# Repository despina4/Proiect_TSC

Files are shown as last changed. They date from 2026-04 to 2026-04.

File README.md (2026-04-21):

# Documentatie Hardware - Proiect Wearable / Smartwatch nRF52840

## 1. Diagrama Bloc

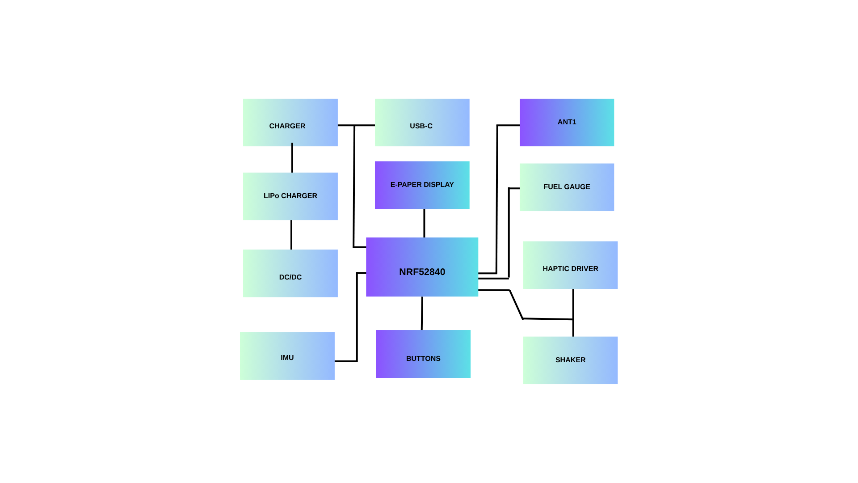
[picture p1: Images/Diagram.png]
Diagrama_bloc


Diagrama ilustreaza doua fluxuri principale:
*   **Fluxul de Alimentare:** De la portul USB-C, prin circuitul de incarcare, catre baterie si apoi prin convertorul DC/DC catre restul componentelor.
*   **Fluxul de Date/Control:** Centrat pe microcontrolerul nRF52840, care comunica cu senzorii, display-ul.

---

## 2. Bill of Materials (BOM)

Tabelul de mai jos contine modulele principale folosite in proiect, impreuna cu link-uri pentru achizitie si specificatii tehnice.

| Nume produs | Ref | Link achizitionare | Datasheet |
| :--- | :--- | :--- | :--- |
| **nRF52840-QIAA** | U1 | [Component Search Engine](https://componentsearchengine.com/part-view/NRF52840-QIAA-R/Nordic%20Semiconductor) | [Datasheet](https://4donline.ihs.com/images/VipMasterIC/IC/NRSA/NRSA-S-A0021008244/NRSA-S-A0021008244-1.pdf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) |
| **BQ25180YBGR** | IC1 | [Component Search Engine](https://componentsearchengine.com/search?term=BQ25180YBGR) | [Datasheet](https://analytics.supplyframe.com/trackingservlet/track/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) |
| **DRV2605YZFR** | IC2 | [Component Search Engine](https://componentsearchengine.com/search?term=DRV2605YZFR) | [Datasheet](https://analytics.supplyframe.com/trackingservlet/track/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) |
| **BMA423** | IC3 | [Component Search Engine](https://componentsearchengine.com/search?term=bma423) | [Datasheet](https://analytics.supplyframe.com/trackingservlet/track/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) |
| **RT6160AWSC** | IC9 | [Component Search Engine](https://componentsearchengine.com/part-view/RT6160AWSC/RICHTEK) | [Datasheet](https://analytics.supplyframe.com/trackingservlet/track/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) |
| **MAX17048G+** | U3 | [Component Search Engine](https://componentsearchengine.com/part-view/MAX17048G%2B/Analog%20Devices) | [Datasheet](https://analytics.supplyframe.com/trackingservlet/track/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) |
| **USB4105-GF-A** | J4 | [SnapMagic](https://www.snapeda.com/parts/USB4105-GF-A/GCT/view-part/?ref=search&t=USB4105-GF-A&ab_test_case=b) | [Datasheet](https://www.snapeda.com/parts/USB4105-GF-A/GCT/datasheet/) |
| **503480-2400** | J1 | [Component Search Engine](https://componentsearchengine.com/part-view/503480-2400/Molex) | [Datasheet](https://analytics.supplyframe.com/trackingservlet/track/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) |
| **EVP-AKE31A** | SW_x | [Component Search Engine](https://componentsearchengine.com/part-view/EVPAKE31A/Panasonic) | [Datasheet](https://analytics.supplyframe.com/trackingservlet/track/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) |
| **2450AT18B100E** | ANT1 | [Component Search Engine](https://componentsearchengine.com/part-view/2450AT18B100E/JOHANSON%20TECHNOLOGY) | [Datasheet](https://analytics.supplyframe.com/trackingservlet/track/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) |
| **02016D105KAT4A** | Cap | [Component Search Engine](https://componentsearchengine.com/part-view/02016D105KAT4A/Kyocera%20AVX) | [Datasheet](https://analytics.supplyframe.com/trackingservlet/track/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) |
| **0402B472K500NT** | Cap | [Component Search Engine](https://componentsearchengine.com/part-view/0402B472K500NT/Guangdong%20Fenghua%20Advanced%20Tech) | [Datasheet](https://analytics.supplyframe.com/trackingservlet/track/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) |
| **0603N101Z160PHT** | Cap | [Component Search Engine](https://componentsearchengine.com/part-view/0603N101Z160PHT/Knowles) | [Datasheet](https://analytics.supplyframe.com/trackingservlet/track/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) |
| **MBR0530** | D_x | [Component Search Engine](https://componentsearchengine.com/part-view/MBR0530/MCC) | [Datasheet](https://analytics.supplyframe.com/trackingservlet/track/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) |
| **USBLC6-2SC6Y** | D3 | [Component Search Engine](https://componentsearchengine.com/part-view/USBLC6-2SC6Y/STMicroelectronics) | [Datasheet](https://analytics.supplyframe.com/trackingservlet/track/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) |
| **HT7750A SOT23-3** | Q1 | [Component Search Engine](https://componentsearchengine.com/part-view/HT7750A%20SOT23-3/Holtek) | [Datasheet](#) |
| **SI1308EDL** | Q3 | [Component Search Engine](https://componentsearchengine.com/part-view/SI1308EDL-T1-GE3/Vishay) | [Datasheet](https://analytics.supplyframe.com/trackingservlet/track/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) |
| **NX2016SA-32MHZ** | X1 | [Component Search Engine](https://componentsearchengine.com/part-view/NX2016SA-32MHZ-EXS00A-CS11336/NDK) | [Datasheet](https://analytics.supplyframe.com/trackingservlet/track/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) |
| **ABS07-32.768KHZ** | X2 | [Component Search Engine](https://componentsearchengine.com/part-view/ABS0732768KHZT/ABRACON) | [Datasheet](https://analytics.supplyframe.com/trackingservlet/track/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) |
| **WE-TPC 4828** | L5 | [SnapMagic](https://www.snapeda.com/parts/744043004/W%C3%BCrth%20Elektronik/view-part/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) | [Datasheet](https://www.snapeda.com/parts/744043004/W%C3%BCrth%20Elektronik/datasheet/) |
| **MLP2016SR47M** | L7 | [Component Search Engine](https://componentsearchengine.com/part-view/MLP2016SR47MT0S1/TDK) | [Datasheet](https://analytics.supplyframe.com/trackingservlet/track/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) |

---
## 3. Detalii Tehnice Hardware

### A. Centrul de Procesare si Comunicatie
*   **MCU Nordic nRF52840:**
    - System on Chip -> gestioneaza stack-ul de comunicatie Bluetooth 5.0, procesarea semnalelor de la senzori si controlul logic al alimentarii.
*   **Conectivitate:**
    - Include ANT1 pentru transmisiuni BLE stabile, cu o zona de decupare dedicata in planul de masa.

### B. Subsistemul de Afisare si Interactiune (UI/UX)
*   **Tehnologie E-Paper (SPI):** 
    - Ecran bi-stabil pentru a elimina consumul de energie in mod static. Imaginea ramane pe ecran fara alimentare (economisire pana la refresh).
*   **Feedback Tactil (I2C):** 
    - **DRV2605** actioneaza un motor de vibratii tip ERM, astfel permite  notificari tactile.
*   **Control Manual:** 
     - Navigarea este realizata prin 3 butoane mecanice, switch-urile.

### C. Detectie Miscare si Monitorizare
*   **BMA423:** 
    - Senzor inteligent -> pedometru 
*   **FuelGauge:**-> determina procentul de incarcare al bateriei
### D. Alimentare + Protectie
* **Charger** 
    - Incarca bateria prin USB-C si o protejeaza.
* **DC/DC**
    -  Mentine curentul fix la 3.3V pentru toate piesele.
* **Dioda**
    - Protejeaza placa de socuri electrice la mufa USB
---

## 4. Alocare Pini nRF52840

| Pin | Semnal | Functionalitate |
| :--- | :--- | :--- |
| **P0.00 / 0.01** | XL1 / XL2 | Conexiune cristal  |
| **P0.02** | SCK | SPI Clock  |
| **P0.03** | MOSI | SPI Data MOSI |
| **P0.05** | EPD_CS | SPI Chip Select |
| **P0.08** | IMU_INT1 | Intrerupere 1 -> senzor BMA423 |
| **P0.10** | ALERT | Semnal de alerta sistem |
| **P0.15** | EPD_DC | SPI Data/Command |
| **P0.16** | EPD_RST | Reset hardware Display |
| **P0.17** | EPD_BUSY | Status Display|
| **P0.18** | RESET | Reset sistem  |
| **P1.00** | SW_ENT | Buton ENTER|
| **P0.13** | SW_UP | Buton UP|
| **P0.14** | SW_DN | Buton DOWN|
| **P0.11** | PMIC_INT | Intrerupere management baterie|
| **P0.12** | HAPTIC_EN | Semnal Enable driver haptic|
| **P1.08** | IMU_INT2 | Intrerupere 2 -> senzor BMA423|
| **P0.06** | SDA | Date I2C |
| **P0.07** | SCL | Clock I2C. |

---
## 5. Design 
- Rutarea am realizat-o manual, pe 3 layere :TOP, BOTTOM, GND.
- In momentul generarii planului de masa (GND copper pour), am creat o zona de cutout polygon in dreptul antenei.Am luat aceasta masura  pentru a preveni ecranarea sau  detuning ul antenei de catre planul de cupru adiacent.

## 6. Erori DRC marcate ca APPROVED
Din cauza dimensiunilor foarte mici, am dat approve la cateva erori manual, ignorand erorile DRC :

*   **Copper Clearance (IC2):** Am acceptat 4 erori pentru a permite width de 0.3 mm pentru power traces (VBUS, 3V3).
*   **Via Overlap:** Pentru a conecta componentele din mijlocul componenetelor, cat si cele care nu erau accesibile altfel, am fost constransa sa pun via-uri peste componenta. 
---

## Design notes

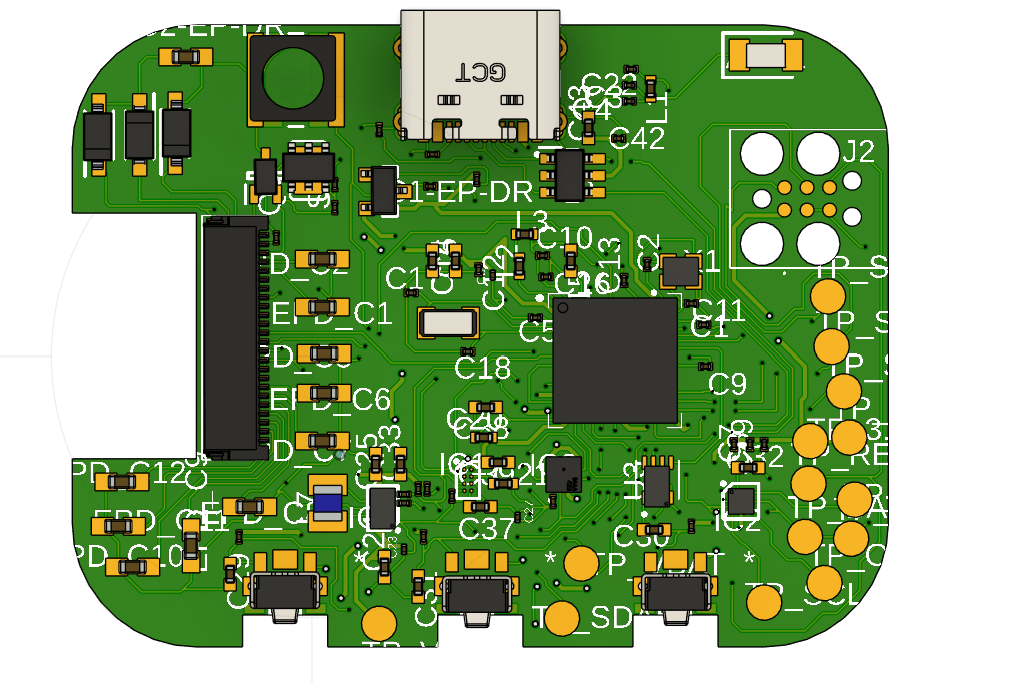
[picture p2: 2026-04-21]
Images/top_view_3D.png

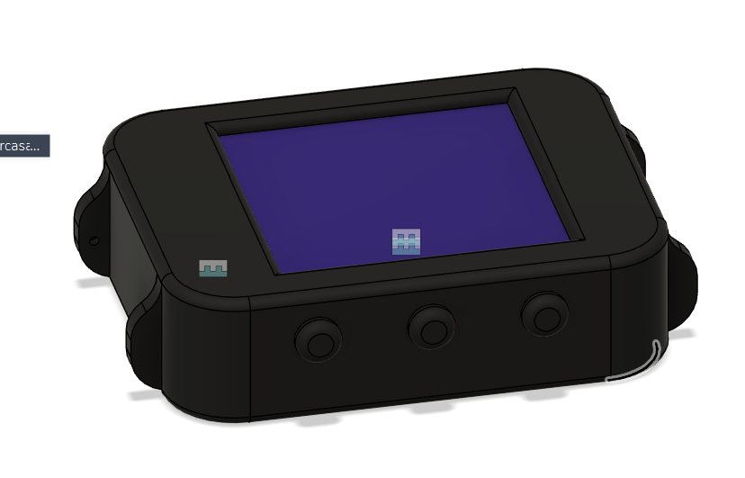
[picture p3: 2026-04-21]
Images/pcb_3d_locked - Copy.png

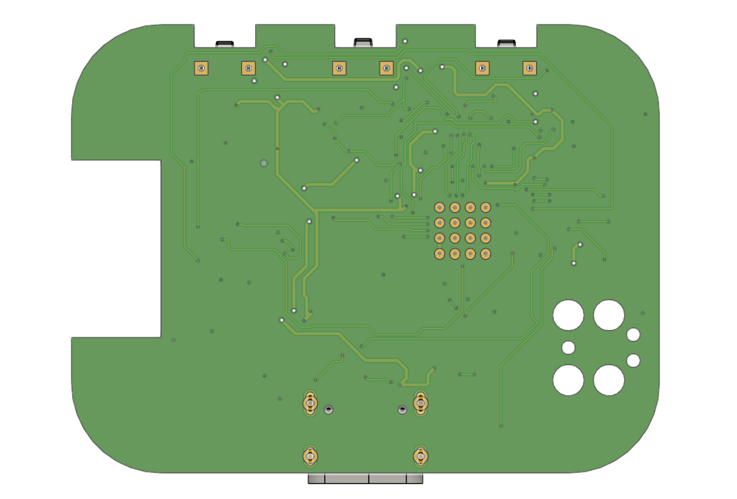
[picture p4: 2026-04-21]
Images/bottom_view_3D.png

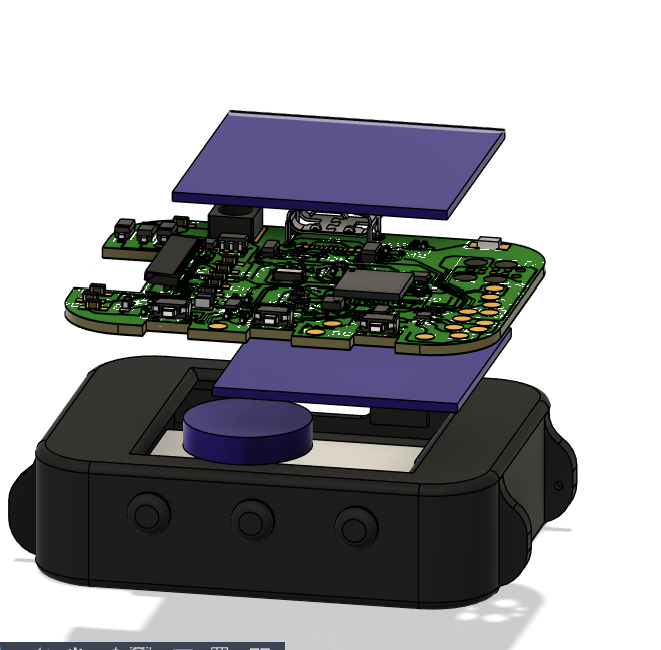
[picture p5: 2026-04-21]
Images/PCB_3D_complete_exterior_view.png

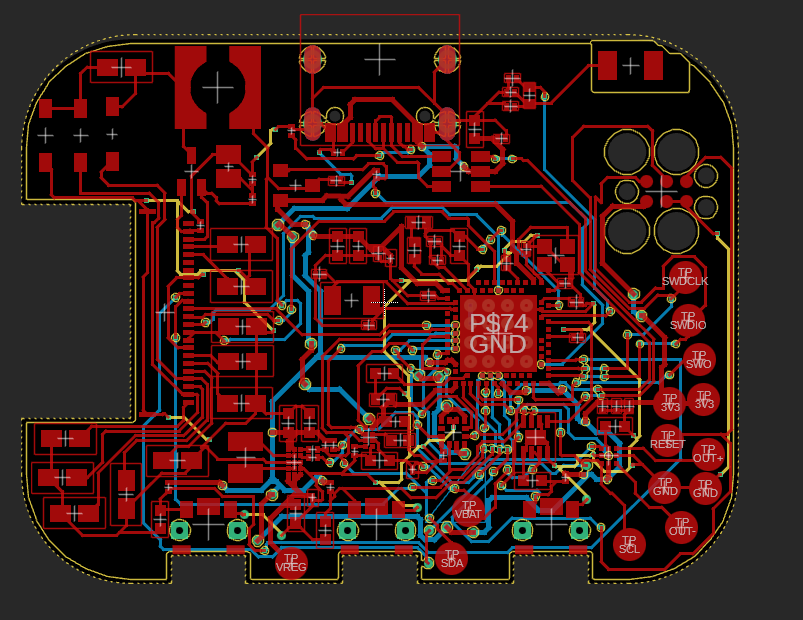
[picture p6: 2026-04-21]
Images/pcb_rutare.png

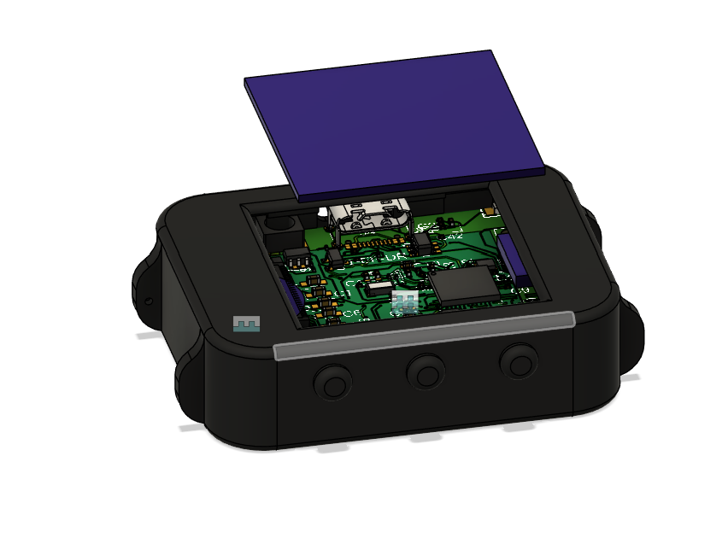
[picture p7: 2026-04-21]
Images/PCB_3D_complete.png

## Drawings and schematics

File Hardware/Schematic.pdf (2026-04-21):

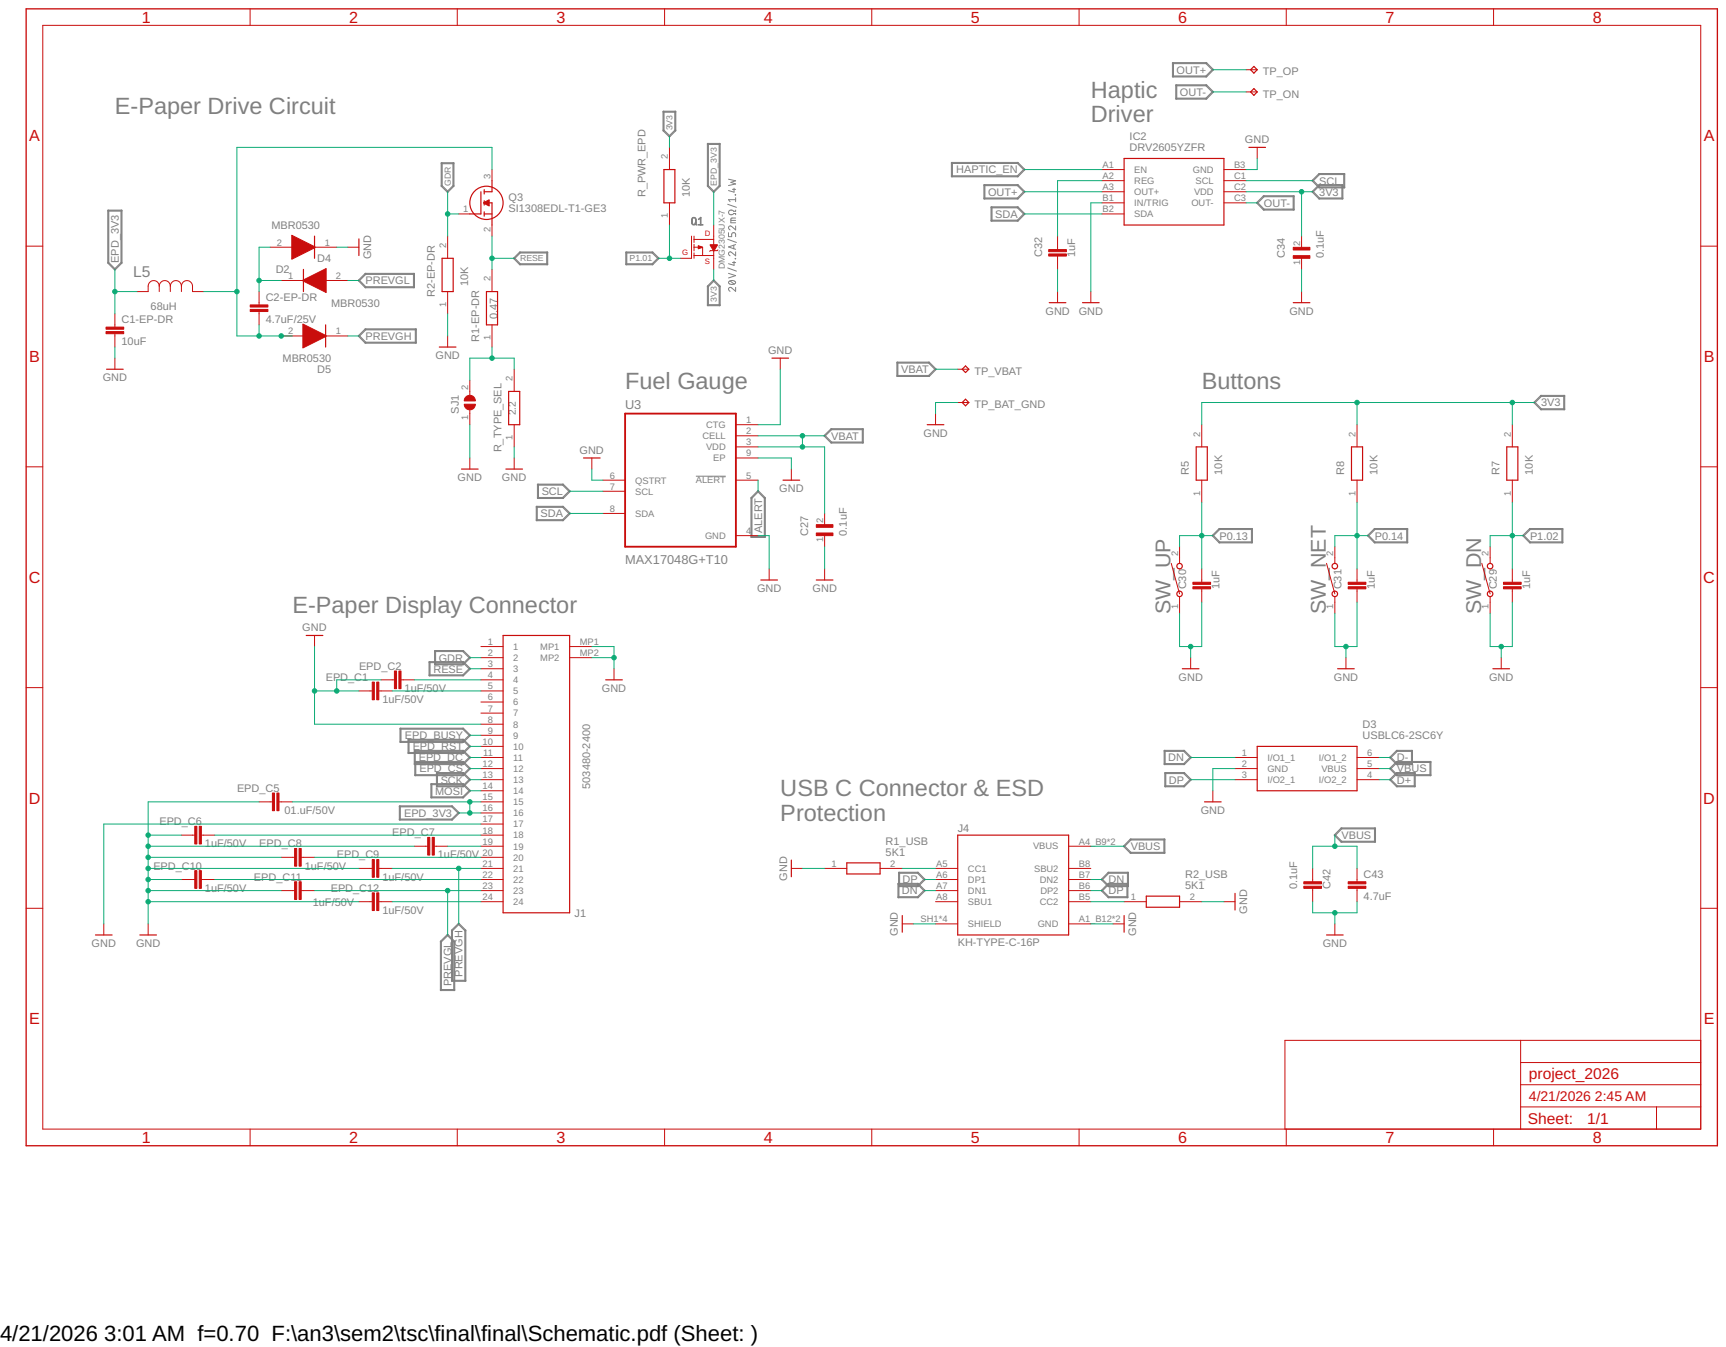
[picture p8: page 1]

4/21/2026 3:01 AM f=0.70 F:\an3\sem2\tsc\final\final\Schematic.pdf (Sheet: )

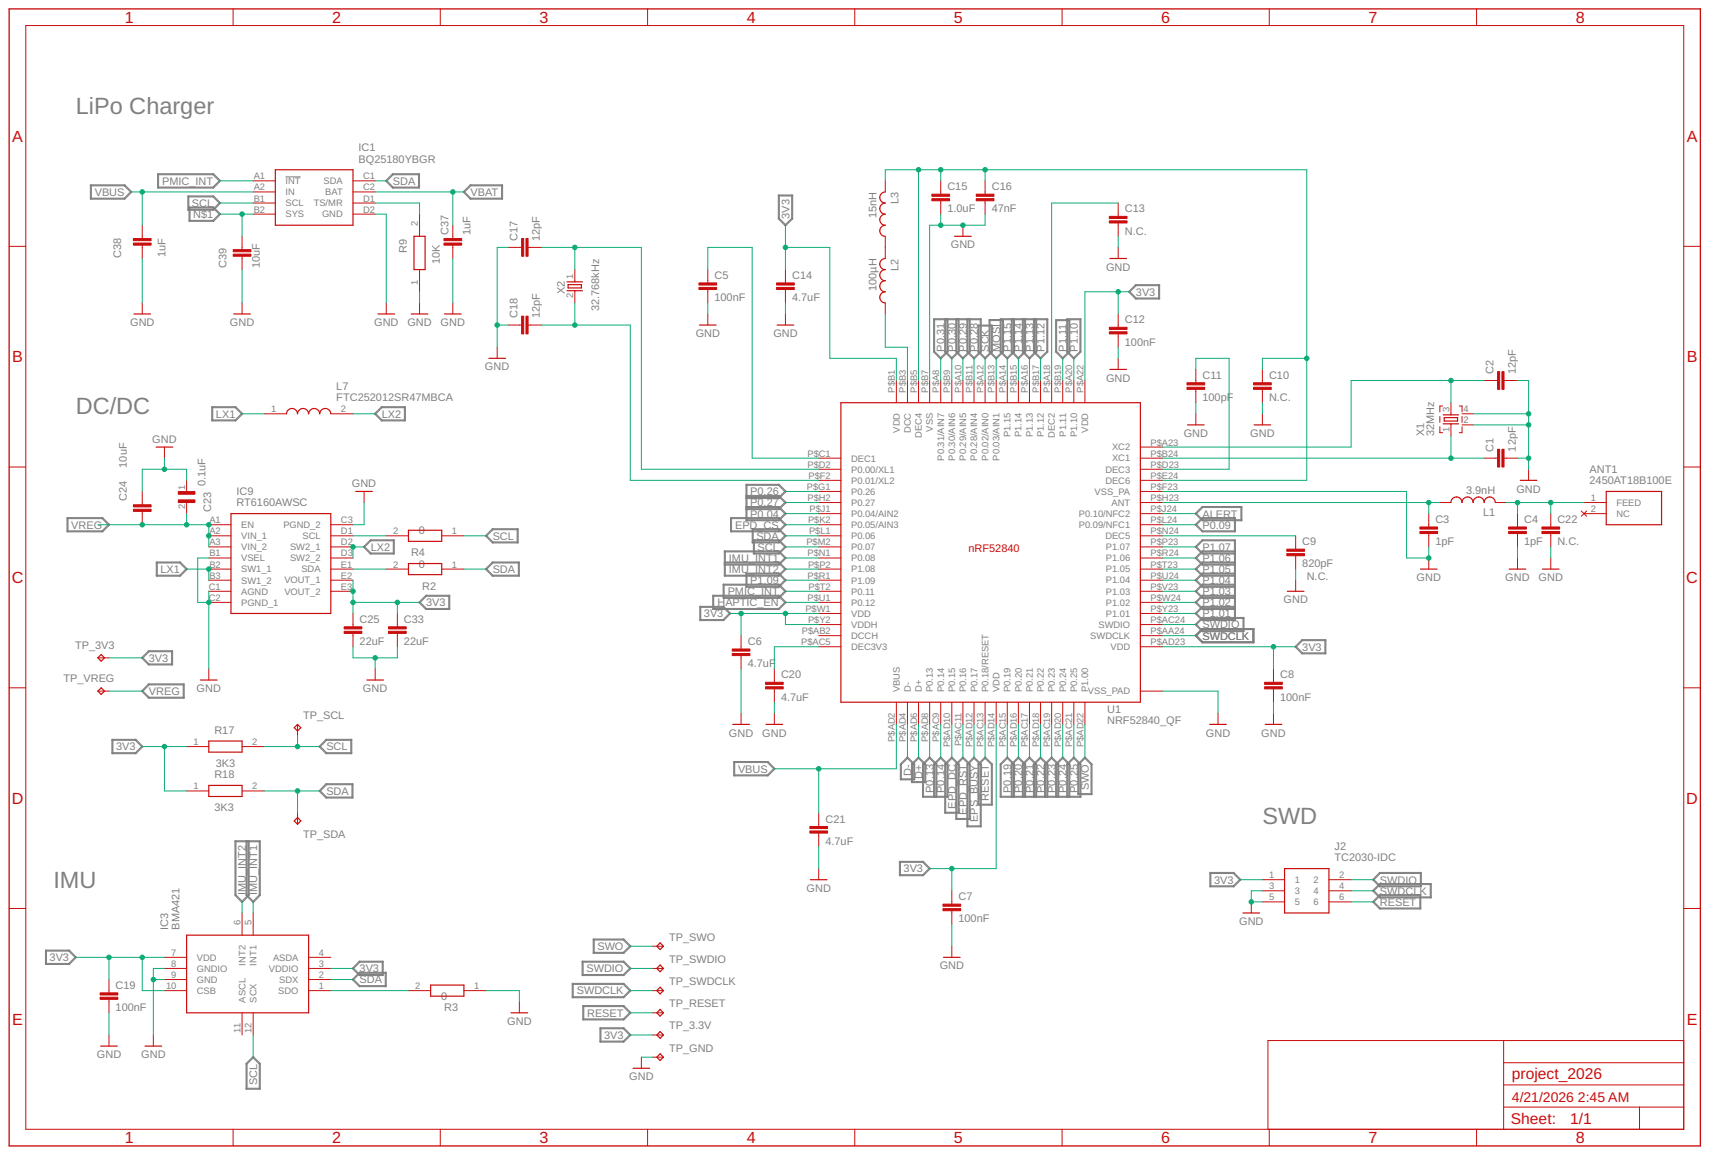
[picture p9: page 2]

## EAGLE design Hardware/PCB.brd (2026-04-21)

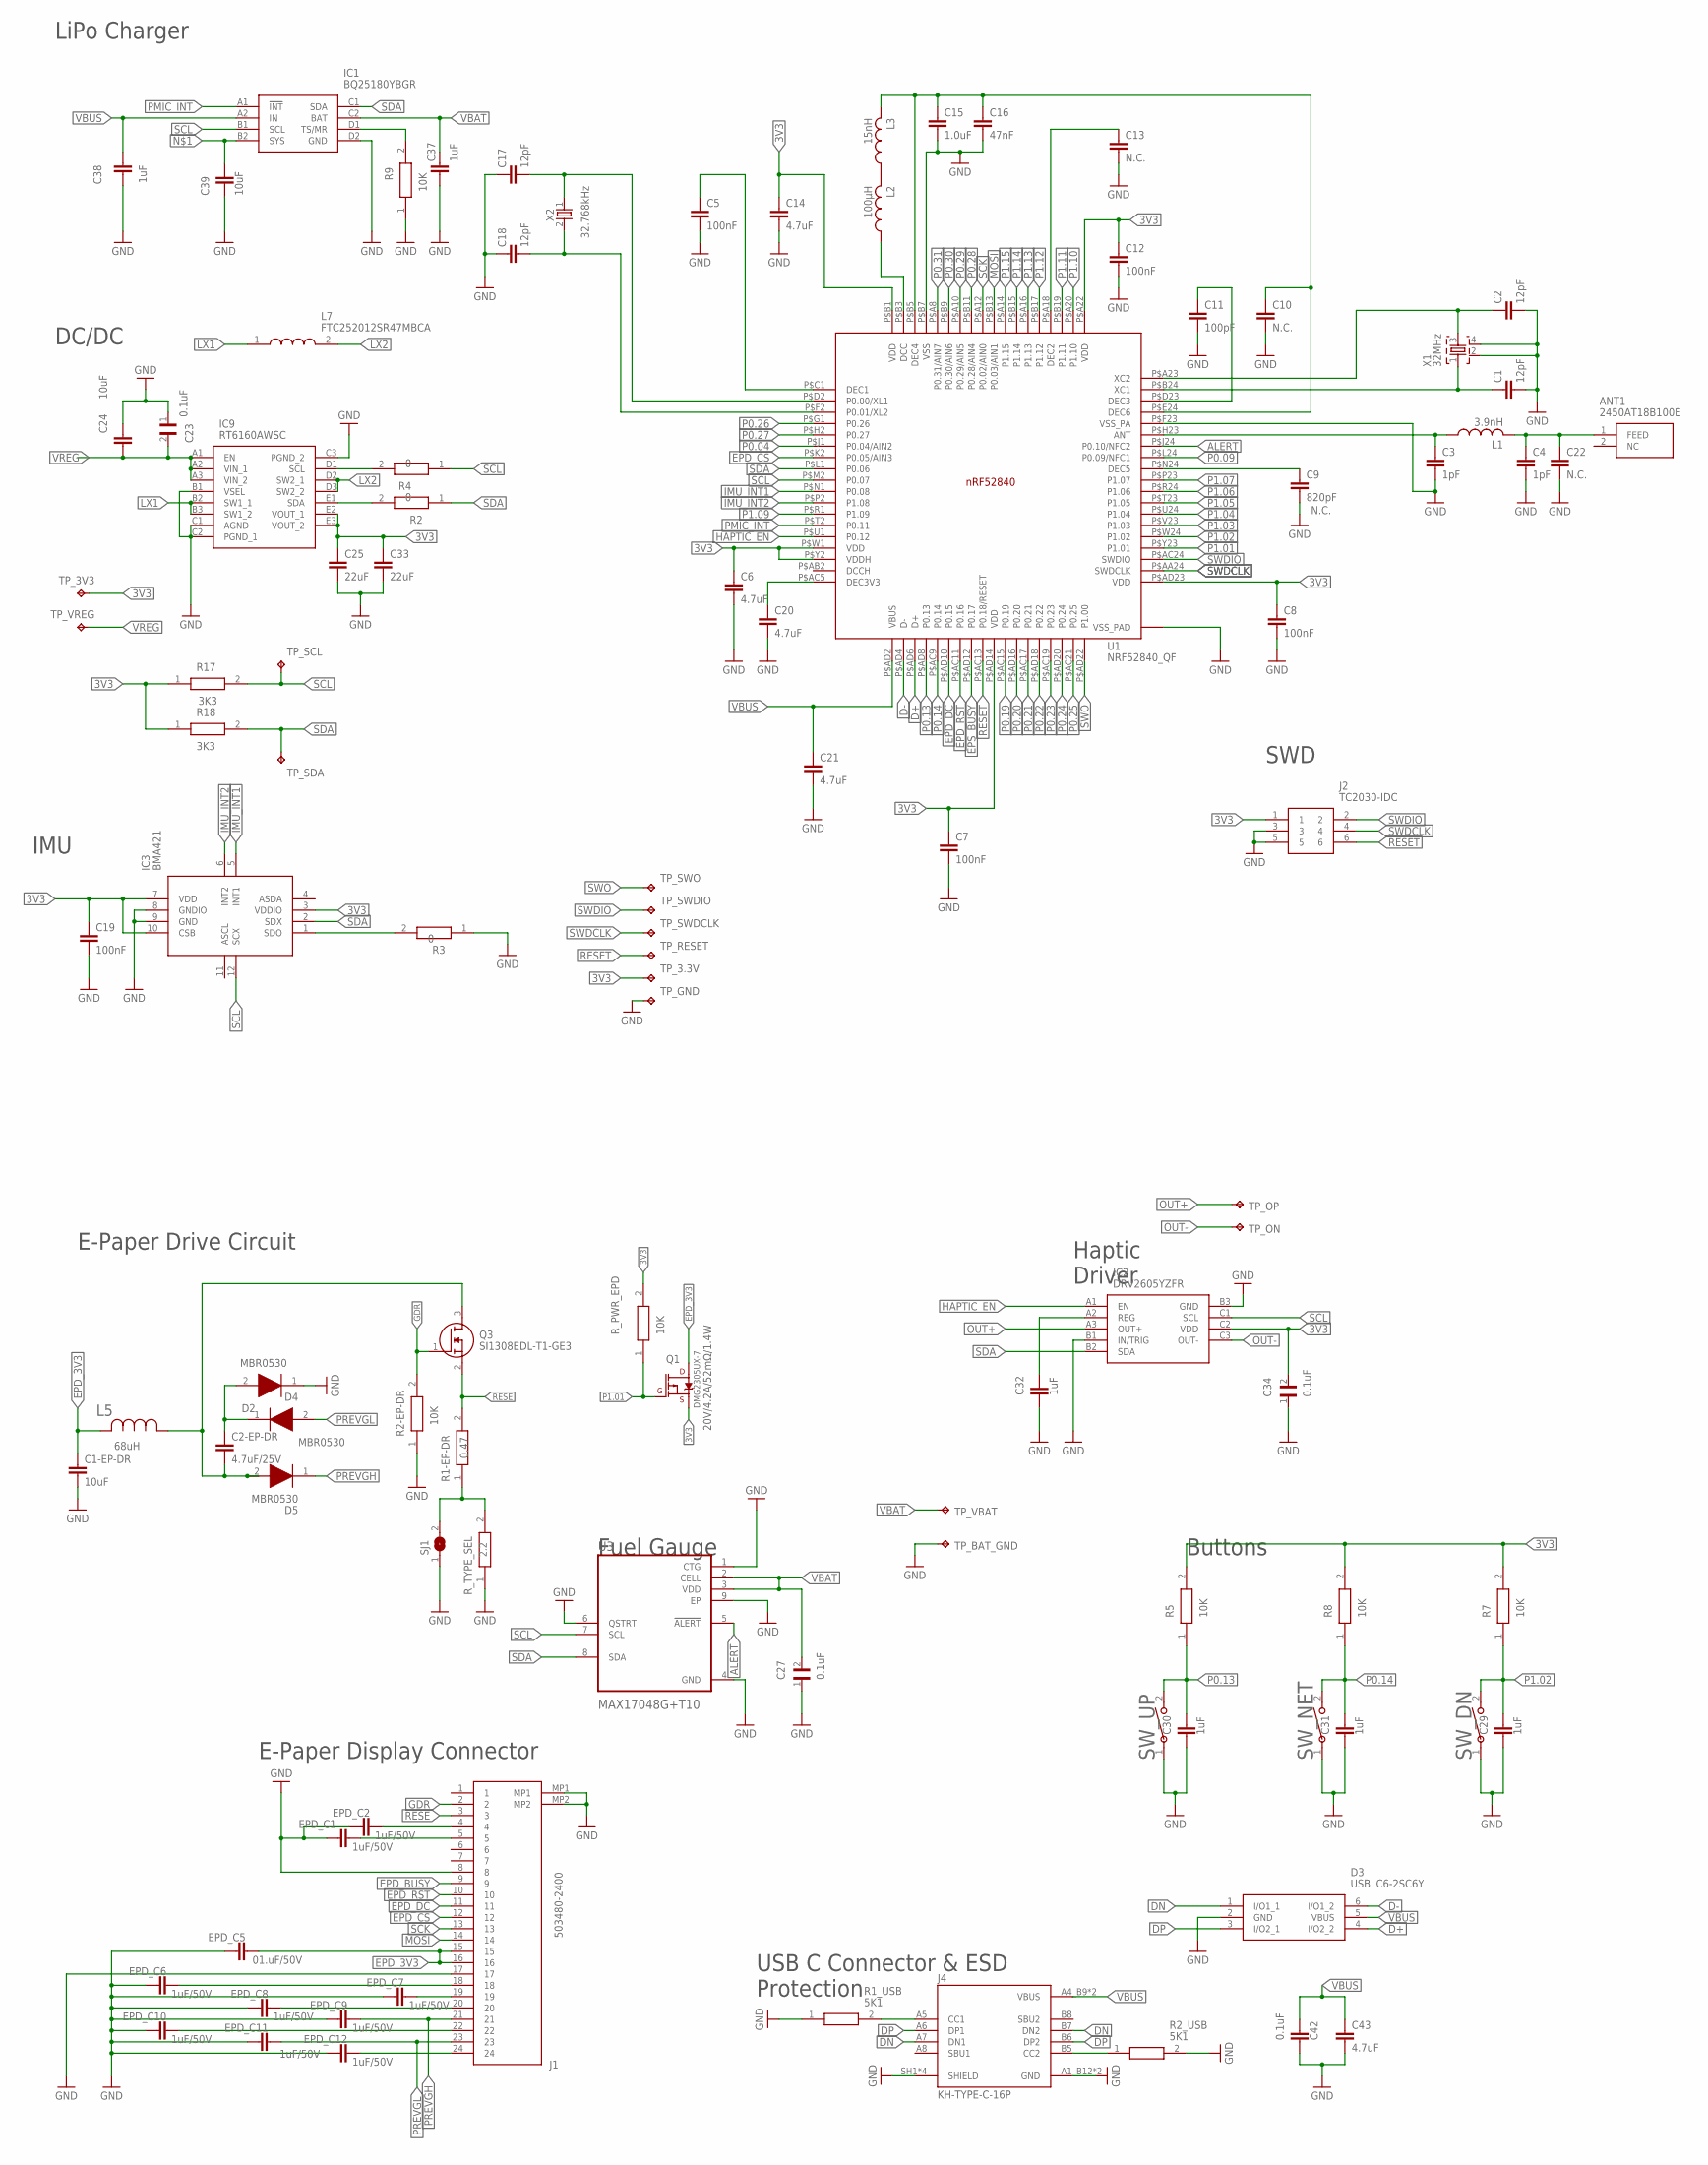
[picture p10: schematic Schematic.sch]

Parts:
ANT1: 2450AT18B100E; 2450AT18B100E_ANTC3216X140N
C1, C2, C17, C18: 12pF; NORDIC_NRF_3_RESC0201_L
C1-EP-DR: 10uF; NORDIC_NRF_3_RESC0201_L
C2-EP-DR: 4.7uF/25V; NORDIC_NRF_3_RESC0603_M
C3, C4: 1pF; NORDIC_NRF_3_RESC0201_L
C5, C7, C8, C12, C19: 100nF; NORDIC_NRF_3_RESC0201_L
C6, C14, C20, C21, C43: 4.7uF; NORDIC_NRF_3_RESC0402_M
C9: 820pF; NORDIC_NRF_3_RESC0201_L
C10, C13, C22: N.C.; NORDIC_NRF_3_RESC0201_L
C11: 100pF; NORDIC_NRF_3_RESC0201_L
C15: 1.0uF; NORDIC_NRF_3_RESC0402_M
C16: 47nF; NORDIC_NRF_3_RESC0201_L
C23, C27, C34: 0.1uF; GRM011R60J152KE01L_2_CAPC0201X13N
C24: 10uF; NORDIC_NRF_3_RESC0402_M
C25, C33: 22uF; NORDIC_NRF_3_RESC0402_M
C29, C30, C31, C32, C37: 1uF; NORDIC_NRF_3_RESC0402_M
C38: 1uF; NORDIC_NRF_3_RESC0402_L
C39: 10uF; NORDIC_NRF_3_RESC0402_N
C42: 0.1uF; NORDIC_NRF_3_RESC0201_L
D2, D4, D5: MBR0530; ESP32_C6_LIBRARY_5_SOD3716X135N
D3: USBLC6-2SC6Y; ESP32_C6_LIBRARY_3_SOT95P280X145-6N
EPD_C1, EPD_C2, EPD_C6, EPD_C7, EPD_C8, EPD_C9, EPD_C10, EPD_C11, EPD_C12: 1uF/50V; NORDIC_NRF_3_RESC0603_M
EPD_C5: 01.uF/50V; NORDIC_NRF_3_RESC0603_M
IC1: BQ25180YBGR; BQ25180YBGR_BGA8C40P2X4_100X155X50
IC2: DRV2605YZFR; DRV2605YZFR_BGA9C50P3X3_144X144X62
IC3: BMA421; BMA423_BMA423
IC9: RT6160AWSC; RT6160AWSC_BGA15C40P3X5_140X230X60
J1: 503480-2400; 503480-2400_5034802400
J2: TC2030-IDC; TC2030-IDC_TC2030IDC
J4: KH-TYPE-C-16P; KH-TYPE-C-16P_KINGHELM_KH-TYPE-C-16P
L1: 3.9nH; NORDIC_NRF_2_RESC0402_L
L2: 100µH; NORDIC_NRF_2_RESC0402_L
L3: 15nH; NORDIC_NRF_2_RESC0402_L
L5: 68uH; ESP32_C6_LIBRARY_2_IND_4828-WE-TPC_WRE
L7: FTC252012SR47MBCA; MLP2016SR47MT0S1_INDC2016X100N
Q1: 20V/4.2A/52mΩ/1.4W; ESP32_C6_LIBRARY_4_ESP32_C6_LIBRARY_4_ESP32_C6_LIBRARY_4_ES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
Q3: SI1308EDL-T1-GE3; ESP32_C6_LIBRARY_6_SOT65P210X110-3N
R1-EP-DR: 0.47; ERA-1AEB3401C_0201
R1_USB, R2_USB: 5K1; ERA-1AEB3401C_0201
R2, R3, R4: 0; ERA-1AEB3401C_0201
R2-EP-DR, R5, R7, R8, R9: 10K; ERA-1AEB3401C_0201
R17, R18: 3K3; ERA-1AEB3401C_0201
R_PWR_EPD: 10K; ERA-1AEB3401C_0201
R_TYPE_SEL: 2.2; ERA-1AEB3401C_0201
SJ1: ESP32_C6_LIBRARY_7_JUMPER_SJ
SW_DN: 2025-10-22_07-23-44_LIBRARY_EVP-AKE31ASW_EVP-AKE3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; 2025-10-22_07-23-44_LIBRARY_SW_EVP-AKE31A_PAN
SW_NET: 2025-10-22_07-23-44_LIBRARY_EVP-AKE31ASW_EVP-AKE3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; 2025-10-22_07-23-44_LIBRARY_SW_EVP-AKE31A_PAN
SW_UP: 2025-10-22_07-23-44_LIBRARY_EVP-AKE31ASW_EVP-AKE3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; 2025-10-22_07-23-44_LIBRARY_SW_EVP-AKE31A_PAN
TP_3.3V, TP_3V3: HECTOR_WATCH_1_TPTP20R; HECTOR_WATCH_1_TP20R
TP_BAT_GND: HECTOR_WATCH_1_TPTP20R; HECTOR_WATCH_1_TP20R
TP_GND: HECTOR_WATCH_1_TPTP20R; HECTOR_WATCH_1_TP20R
TP_ON: HECTOR_WATCH_1_TPTP20R; HECTOR_WATCH_1_TP20R
TP_OP: HECTOR_WATCH_1_TPTP20R; HECTOR_WATCH_1_TP20R
TP_RESET: HECTOR_WATCH_1_TPTP20R; HECTOR_WATCH_1_TP20R
TP_SCL: HECTOR_WATCH_1_TPTP20R; HECTOR_WATCH_1_TP20R
TP_SDA: HECTOR_WATCH_1_TPTP20R; HECTOR_WATCH_1_TP20R
TP_SWDCLK: HECTOR_WATCH_1_TPTP20R; HECTOR_WATCH_1_TP20R
TP_SWDIO: HECTOR_WATCH_1_TPTP20R; HECTOR_WATCH_1_TP20R
TP_SWO: HECTOR_WATCH_1_TPTP20R; HECTOR_WATCH_1_TP20R
TP_VBAT: HECTOR_WATCH_1_TPTP20R; HECTOR_WATCH_1_TP20R
TP_VREG: HECTOR_WATCH_1_TPTP20R; HECTOR_WATCH_1_TP20R
U1: NRF52840_QF; NORDIC_NRF_4_AQFN50P700X700X85_HS-74N
U3: MAX17048G+T10; ESP32_C6_LIBRARY_SON50P200X200X80-9N
X1: 32MHz; NORDIC_NRF_BT-XTAL_2016_N
X2: 32.768kHz; NORDIC_NRF_1_XTAL_3215_N

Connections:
3V3: C6.1, C7.1, C8.1, C12.1, C14.1, C19.1, C25.1, C33.1, C34.2, IC2.C2 (VDD), IC3.3 (VDDIO), IC3.7 (VDD), IC3.10 (CSB), IC9.E2 (VOUT_1), IC9.E3 (VOUT_2), J2.1, Q1.2 (S), R5.2, R7.2, R8.2, R17.1, R18.1, R_PWR_EPD.2, TP_3.3V.TP, TP_3V3.TP, U1.P$A22 (VDD), U1.P$AD14 (VDD), U1.P$AD23 (VDD), U1.P$B1 (VDD), U1.P$W1 (VDD), U1.P$Y2 (VDDH)
ALERT: U1.P$J24 (P0.10/NFC2), U3.5 (!ALERT)
D+: D3.4 (I/O2_2), U1.P$AD6 (D+)
D-: D3.6 (I/O1_2), U1.P$AD4 (D-)
DN: D3.1 (I/O1_1), J4.A7 (DN1), J4.B7 (DN2)
DP: D3.3 (I/O2_1), J4.A6 (DP1), J4.B6 (DP2)
EPD_3V3: C1-EP-DR.1, EPD_C5.2, J1.15, J1.16, L5.2, Q1.3 (D)
EPD_BUSY: J1.9
EPD_CS: J1.12, U1.P$K2 (P0.05/AIN3)
EPD_DC: J1.11, U1.P$AD10 (P0.15)
EPD_RST: J1.10, U1.P$AC11 (P0.16)
EPS_BUSY: U1.P$AD12 (P0.17)
GDR: J1.2, Q3.1 (G), R2-EP-DR.2
GND: C1.2, C1-EP-DR.2, C2.2, C3.2, C4.2, C5.2, C6.2, C7.2, C8.2, C9.2, C10.2, C11.2, C12.2, C13.2, C14.2, C15.2, C16.2, C17.1, C18.1, C19.2, C20.2, C21.2, C22.2, C23.1, C24.1, C25.2, C27.1, C29.2, C30.2, C31.2, C32.2, C33.2, C34.1, C37.2, C38.1, C39.2, C42.2, C43.2, D3.2 (GND), D4.1 (K), EPD_C1.1, EPD_C2.1, EPD_C5.1, EPD_C6.1, EPD_C7.1, EPD_C8.1, EPD_C9.1, EPD_C10.1, EPD_C11.1, EPD_C12.1, IC1.D2 (GND), IC2.B1 (IN/TRIG), IC2.B3 (GND), IC3.8 (GNDIO), IC3.9 (GND), IC9.B1 (VSEL), IC9.C1 (AGND), IC9.C2 (PGND_1), IC9.C3 (PGND_2), J1.8, J1.17, J1.MP1, J1.MP2, J2.3, J2.5, J4.A1_B12 (GND), J4.A12_B1 (GND), J4.SH1 (SHIELD), J4.SH2 (SHIELD), J4.SH3 (SHIELD), J4.SH4 (SHIELD), R1_USB.1, R2-EP-DR.1, R2_USB.2, R3.1, R9.1, R_TYPE_SEL.1, SJ1.1, SW_DN.1, SW_NET.1, SW_UP.1, TP_BAT_GND.TP, TP_GND.TP, U1.P$74 (VSS_PAD), U1.P$75 (VSS_PAD), U1.P$76 (VSS_PAD), U1.P$77 (VSS_PAD), U1.P$78 (VSS_PAD), U1.P$79 (VSS_PAD), U1.P$80 (VSS_PAD), U1.P$81 (VSS_PAD), U1.P$82 (VSS_PAD), U1.P$83 (VSS_PAD), U1.P$84 (VSS_PAD), U1.P$85 (VSS_PAD), U1.P$86 (VSS_PAD), U1.P$87 (VSS_PAD), U1.P$88 (VSS_PAD), U1.P$89 (VSS_PAD), U1.P$90 (VSS_PAD), U1.P$B7 (VSS), U1.P$F23 (VSS_PA), U3.1 (CTG), U3.4 (GND), U3.6 (QSTRT), U3.9 (EP), X1.2, X1.4
HAPTIC_EN: IC2.A1 (EN), U1.P$U1 (P0.12)
IMU_INT1: IC3.5 (INT1), U1.P$N1 (P0.08)
IMU_INT2: IC3.6 (INT2), U1.P$P2 (P1.08)
LX1: IC9.B2 (SW1_1), IC9.B3 (SW1_2), L7.1
LX2: IC9.D2 (SW2_1), IC9.D3 (SW2_2), L7.2
MOSI: J1.14, U1.P$B13 (P0.03/AIN1)
unnamed: C39.1, IC1.B2 (SYS)
unnamed: C5.1, U1.P$C1 (DEC1)
unnamed: IC9.D1 (SCL), R4.2
unnamed: IC9.E1 (SDA), R2.2
unnamed: C17.2, U1.P$D2 (P0.00/XL1), X2.1
unnamed: IC1.D1 (TS/MR), R9.2
unnamed: ANT1.1 (FEED), C4.1, C22.1, L1.2
unnamed: EPD_C8.2, J1.20
unnamed: L2.1, U1.P$B3 (DCC)
unnamed: IC3.1 (SDO), R3.2
unnamed: C10.1, C15.1, C16.1, L3.2, U1.P$B5 (DEC4), U1.P$E24 (DEC6)
unnamed: L2.2, L3.1
unnamed: C18.2, U1.P$F2 (P0.01/XL2), X2.2
unnamed: C2-EP-DR.2, D5.2 (A), L5.1, Q3.3 (D)
unnamed: C2-EP-DR.1, D2.1 (K), D4.2 (A)
unnamed: EPD_C2.2, J1.4
unnamed: R1-EP-DR.1, R_TYPE_SEL.2, SJ1.2
unnamed: EPD_C12.2, J1.24
unnamed: C9.1, U1.P$N24 (DEC5)
unnamed: EPD_C1.2, J1.5
unnamed: C20.1, U1.P$AC5 (DEC3V3)
unnamed: J4.A5 (CC1), R1_USB.2
unnamed: C3.1, L1.1, U1.P$H23 (ANT)
unnamed: EPD_C10.2, J1.22
unnamed: C11.1, U1.P$D23 (DEC3)
unnamed: C1.1, U1.P$B24 (XC1), X1.1
unnamed: C2.1, U1.P$A23 (XC2), X1.3
unnamed: C32.1, IC2.A2 (REG)
unnamed: C13.1, U1.P$A18 (DEC2)
unnamed: J4.B5 (CC2), R2_USB.1
unnamed: EPD_C6.2, J1.18
unnamed: EPD_C7.2, J1.19
OUT+: IC2.A3 (OUT+), TP_OP.TP
OUT-: IC2.C3 (OUT-), TP_ON.TP
P0.04: U1.P$J1 (P0.04/AIN2)
P0.09: U1.P$L24 (P0.09/NFC1)
P0.13: C30.1, R5.1, SW_UP.2, U1.P$AD8 (P0.13)
P0.14: C31.1, R8.1, SW_NET.2, U1.P$AC9 (P0.14)
P0.19: U1.P$AC15 (P0.19)
P0.20: U1.P$AD16 (P0.20)
P0.21: U1.P$AC17 (P0.21)
P0.22: U1.P$AD18 (P0.22)
P0.23: U1.P$AC19 (P0.23)
P0.24: U1.P$AD20 (P0.24)
P0.25: U1.P$AC21 (P0.25)
P0.26: U1.P$G1 (P0.26)
P0.27: U1.P$H2 (P0.27)
P0.28: U1.P$B11 (P0.28/AIN4)
P0.29: U1.P$A10 (P0.29/AIN5)
P0.30: U1.P$B9 (P0.30/AIN6)
P0.31: U1.P$A8 (P0.31/AIN7)
P1.01: Q1.1 (G), R_PWR_EPD.1, U1.P$Y23 (P1.01)
P1.02: C29.1, R7.1, SW_DN.2, U1.P$W24 (P1.02)
P1.03: U1.P$V23 (P1.03)
P1.04: U1.P$U24 (P1.04)
P1.05: U1.P$T23 (P1.05)
P1.06: U1.P$R24 (P1.06)
P1.07: U1.P$P23 (P1.07)
P1.09: U1.P$R1 (P1.09)
P1.10: U1.P$A20 (P1.10)
P1.11: U1.P$B19 (P1.11)
P1.12: U1.P$B17 (P1.12)
P1.13: U1.P$A16 (P1.13)
P1.14: U1.P$B15 (P1.14)
P1.15: U1.P$A14 (P1.15)
PMIC_INT: IC1.A1 (!INT), U1.P$T2 (P0.11)
PREVGH: D5.1 (K), EPD_C9.2, J1.21
PREVGL: D2.2 (A), EPD_C11.2, J1.23
RESE: J1.3, Q3.2 (S), R1-EP-DR.2
RESET: J2.6, TP_RESET.TP, U1.P$AC13 (P0.18/RESET)
SCK: J1.13, U1.P$A12 (P0.02/AIN0)
SCL: IC1.B1 (SCL), IC2.C1 (SCL), IC3.12 (SCX), R4.1, R17.2, TP_SCL.TP, U1.P$M2 (P0.07), U3.7 (SCL)
SDA: IC1.C1 (SDA), IC2.B2 (SDA), IC3.2 (SDX), R2.1, R18.2, TP_SDA.TP, U1.P$L1 (P0.06), U3.8 (SDA)
SWDCLK: J2.4, TP_SWDCLK.TP, U1.P$AA24 (SWDCLK)
SWDIO: J2.2, TP_SWDIO.TP, U1.P$AC24 (SWDIO)
SWO: TP_SWO.TP, U1.P$AD22 (P1.00)
VBAT: C27.2, C37.1, IC1.C2 (BAT), TP_VBAT.TP, U3.2 (CELL), U3.3 (VDD)
VBUS: C21.1, C38.2, C42.1, C43.1, D3.5 (VBUS), IC1.A2 (IN), J4.A4_B9 (VBUS), J4.A9_B4 (VBUS), U1.P$AD2 (VBUS)
VREG: C23.2, C24.2, IC9.A1 (EN), IC9.A2 (VIN_1), IC9.A3 (VIN_2), TP_VREG.TP

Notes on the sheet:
USB C Connector & ESD Protection
Fuel Gauge
Buttons
Haptic Driver
E-Paper Display Connector
E-Paper Drive Circuit
IMU
SWD
DC/DC
LiPo Charger

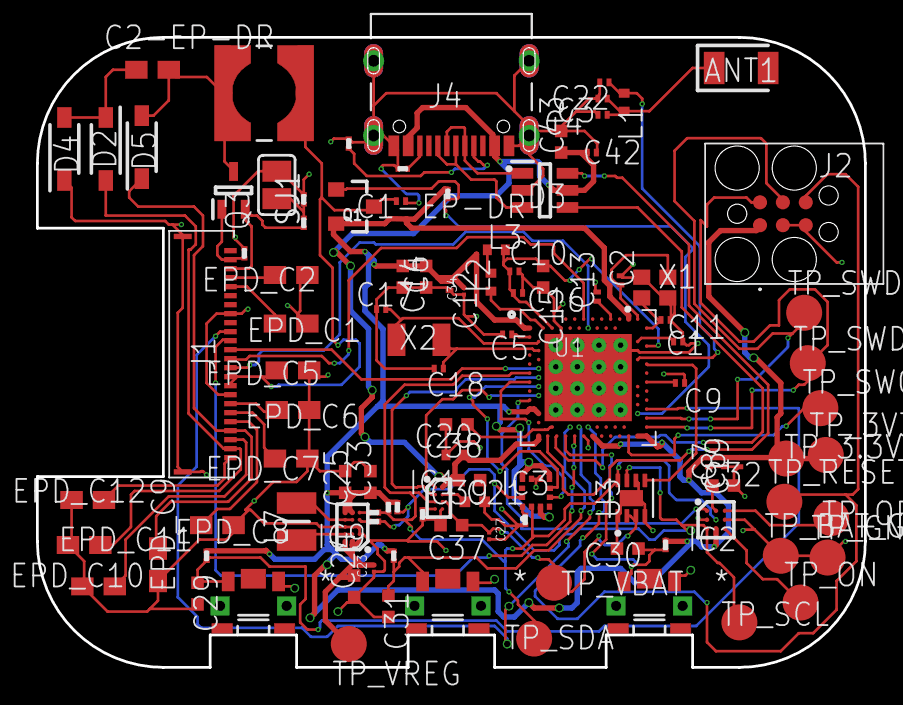
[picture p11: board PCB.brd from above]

Board: 4 copper layers, 46.0 x 35.0 mm, 105 parts (0 on the bottom side), 70 nets.

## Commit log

2026-04-10 Rename Bill _of_Materials.bom to Bill of Materials.bom
2026-04-17 Add files via upload
    schematic final - modificare denumire label
    [Schematic.sch]
2026-04-17 pcb final
    modificare rutare
    [PCB.brd]
2026-04-21 Update Bill of Materials.bom
2026-04-21 varianta finala
    [PCB.brd, Schematic.sch]
2026-04-21 update pentru frame
    adaugare frame schematic

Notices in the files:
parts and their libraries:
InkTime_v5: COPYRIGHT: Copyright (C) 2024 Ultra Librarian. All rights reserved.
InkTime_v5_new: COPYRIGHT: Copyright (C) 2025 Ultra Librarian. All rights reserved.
